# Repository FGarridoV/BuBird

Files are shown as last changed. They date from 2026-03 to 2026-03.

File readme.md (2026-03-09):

# 🐦 BuBird - Smart Birdhouse Observatory
*Welcome to the nest 🪺!*

**BuBird** is an open-source hardware/software project designed to observe the life cycle of local birds in real-time, with near-zero latency, and without invading their natural space. The system combines solar energy and the efficiency of an **ESP32-CAM** with the processing power of a **Raspberry Pi**, offering live video streaming via WebRTC and an remote control Dashboard. 

This project can be a great way to learn many different concepts and topics around Maker and IT culture. At the end, you will be familiar with Docker containers, Cloudflare, Networking, RTSP and UPD server, Python and PlatformIO scripting, Web deployment, 3D printing, hardware setup and more.

In this repository we provide instructions and resources for everyone to implement this project. You are free to choose any bird house, however, we built this project on the [SWEDISH BIRD HOUSE](https://www.thingiverse.com/thing:2503022) contributed by [PurchenZuPoden](https://www.thingiverse.com/PurchenZuPoden/designs) on Thingiverse.

## 🧰 Project requirements

### Hardware
* **Raspberry Pi**: I've used a Pi5 8Gb, But I think with a 3B+, any Pi4 or higher will work.
* **ESP32-CAM**: I've used a clone of the AI Thinker [[buy]](https://amzn.eu/d/01GnobxX)
* **2.4Ghz WiFi Antenna** [[buy]](https://www.otronic.nl/nl/24ghz-wifi-antenne-met-sma-naar-ufl-ipex-connector.html)
* **PIR sensor HC-SR501** [[buy]](https://www.otronic.nl/nl/pir-sensor-hc-sr501-bewegingssensor.html)
* **Solar module CN3065** [[buy]](https://www.otronic.nl/nl/500ma-mini-solar-lipo-lithium-lader-modu-140567801.html)
* **LIPO Baterry** [[buy]](https://www.otronic.nl/nl/37v-4000mah-oplaadbare-lipo-lithium-polyemer-platt.html)
* **Solar Panel**
* **Wires**
* **House pole** [[buy]](https://amzn.eu/d/03isHCS7)

### Tools/materials
* **3D Printer**: I have one Ender3 (v1)
* **Soldering iron**
* **PLA Filament**: I've used Red, White, and Black.
* **Flux paste**
* **Sanding paper**

## 🛠️ System Architecture

The system uses different components to visualize the inside of the bird house autonomusly. The ESP32-CAM record the inside of the house and creates a RTSP server to stream the video to always plugged Raspberry Pi. The Pi captures this streaming and disponbilizes through a web page. The ESP inside the house is solar and battery powered, so, a movement sensor (PIR) controls the camera activity to save energy. Additionally, you can store photos and videos based on some rules to see them later. Finally, the system disponibilizes a local webpage, which it can be safely exposed using CloudFlare. The following Figure summary the full hardware architecture.

uses the ESP32-CAM to record what is happening in

## ✨ Key Features

* 🔋 **Energy Efficiency (Deep Sleep):** Interrupt-based system. The PIR sensor wakes the camera upon detecting motion and sends it to sleep after 1 minute of inactivity, maximizing battery life.
* ⚡ **Ultra-Low Latency Streaming:** Real-time video transmission using RTSP converted to WebRTC via MediaMTX, allowing you to watch the nest without delay.
* 🧠 **State Machine (Auto/Manual):** Take remote control of the camera via UDP, overriding the PIR sensor to keep the system awake on demand.
* 💡 **Soft Flash (PWM):** Gradual toggling of the camera's LED to avoid scaring the birds or causing power spikes (*Brownouts*).
* ☁️ **Over-The-Air Updates (OTA On-Demand):** Integrated with ElegantOTA. The internal web server only spins up when manually activated, freeing up valuable RAM during normal operation.
* 🛡️ **Secure Web Dashboard:** Responsive, multilingual (EN/ES) UI hosted on Nginx with a password-protected control panel. Includes dynamic, real-time system log reading.
* 🪨 **Bulletproof Firmware:** C++ code (PlatformIO) optimized with core separation (FreeRTOS), forced PSRAM, and a 160MHz clock speed to prevent overheating and crashes (*Guru Meditation* errors).

---

## 🛠️ System Architecture

The project is divided into two main blocks:

### 1. The Eye (ESP32-CAM)

Programmed in PlatformIO (`C++`). Manages the camera, PIR sensor, and Wi-Fi connection. It streams RTSP video and communicates with the backend via UDP packets (for logging and receiving commands).

### 2. The Brain (Raspberry Pi / Docker Server)

Orchestrates three Docker containers:

* **MediaMTX:** Receives the RTSP stream from the ESP32-CAM and serves it to the web via WebRTC.
* **Comms Server (Python):** A lightweight UDP/HTTP server that saves logs, auto-discovers the camera's IP, securely verifies web passwords, and sends control commands to the ESP32.
* **Nginx:** Serves the web frontend (HTML/JS/CSS) where users can watch the nest and interact with the admin panel.

---

## 🧰 Hardware Requirements

* 1x **AI-Thinker ESP32-CAM** board (with OV2640 camera module).
* 1x **PIR** Motion Sensor (e.g., AM312 or SR501). Connected to `GPIO 13`.
* 1x Local Server / **Raspberry Pi** (To host the Docker containers).
* High-quality power supply (5V / 2A minimum) for the ESP32.

---

## 🚀 Installation & Deployment

### 1. Flashing the ESP32-CAM

1. Install [Visual Studio Code](https://code.visualstudio.com/) and the [PlatformIO](https://platformio.org/) extension.
2. Open the project's firmware folder.
3. Configure your Wi-Fi credentials and UDP server IP in `src/main.cpp`.
4. Connect the ESP32-CAM and click "Upload". PlatformIO will handle dependencies (ESP32-RTSPServer, ElegantOTA) automatically.

### 2. Deploying the Backend (Docker)

Make sure you have Docker and Docker Compose installed on your Raspberry Pi or local server.

```bash
# Clone the repository
git clone https://github.com/YOUR_USERNAME/BuBird.git
cd BuBird

# Start the services in the background
docker compose up -d

```

### 3. Configuring the Dashboard

1. By default, the admin control panel password is `nido`.
2. To change it, edit the `PASSWORD` variable in `comms/comms_server.py` and restart the container:
`docker restart bubird_comms`

---

## 🎮 Dashboard Usage

Access your Raspberry Pi's IP address in your web browser (e.g., `http://192.168.1.60`).
In the **"Live Cam"** section, expand the *Control Panel* and enter the password to access the Admin options:

* **Automatic:** Normal behavior governed by the PIR sensor.
* **Manual:** Keeps the camera awake and recording indefinitely.
* **Flash:** Turns the LED on/off gradually (Only available in Manual mode).
* **OTA:** Enables the `http://<ESP32_IP>/update` route to flash new firmware over Wi-Fi (Only available in Manual mode).
* **Sleep:** Forces an immediate Deep Sleep.

The system logs terminal on the page interprets these actions in real-time and updates the system status icons accordingly (Sleeping, Live, ⚙️, 🖐️, 💡, ☁️).

---

## 📜 License

This project is open-source. Feel free to clone it, modify it, and use it to observe wildlife in your own backyard!

*Developed with ☕, lots of C++ code, and a passion for nature.*

---

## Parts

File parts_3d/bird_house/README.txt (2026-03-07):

SWEDISH BIRD HOUSE by PurchenZuPoden on Thingiverse: https://www.thingiverse.com/thing:2503022

Summary:
This is a bird house designed to look like a traditional Swedish cottage with a small front porch.You can decide if you want to print the house shell as one piece:gehaeuse_v2or you can print the house shell in 3 parts:Floor: boden_v2Sidewall 1: fasssade_01Sidewall 2: fasssade_02_v2There are also two mounting plates for the house available:montageleiste | for screw mounting (M6 or similar)montageleiste_2 | for zip tie, wire or string mounting What you need:Patience ( My printing time was ~100h)Super GlueA drinking straw (5mm Outer Diameter) for the roof gutterA M6 Screw and nut or something similar to mount the birdhouse to the mounting braket4 M4 Nuts and 4 Screws for the detachable roof I have also used black nail polish and painted the surface for the window and door opening black before i glued the parts to the house.Additional notes:The standard birdhouse hole size is 30mm (einflugring_gewinde) and 45mm (einflugring). Please have a look here for different birdhouse hole sizes if you want to attract a specific bird.: https://www.thespruce.com/bird-house-hole-sizes-386641http://www.vogelhaus-nistkasten.de/nistkaesten/einflugloch-nistkasten/ (For german birds)Please make sure to add support, when you are printing the roof. The roof is the only part of the assembly that needs a little bit of support at the bottom of the print.If you have a woodpecker close by the chances are high, that he will like the sound of the birdhouse and will tear big holes in the walls. It happened to me already two times. I really don't have a solution for that. I printed the  3rd house now with almost 100% infill for the walls. I hope this will help.UPDATE 1:There is a new assembly for the birdhouse hole. (SCREW: einflugring_gewinde  and NUT: einflugring_mutter). You can easily change the hole size for a specific bird type e.g. with the Microsoft 3D Builder.UPDATE 2:If someone does not want to have the water reservoir on the bird house I have added modified partsIf someone wants to have a specific hole diameter, you can use the new file "einflugring_gewinde_without_hole.stl" and add the hole with your specific diameter e.g. with the free Microsoft 3D Builder Software

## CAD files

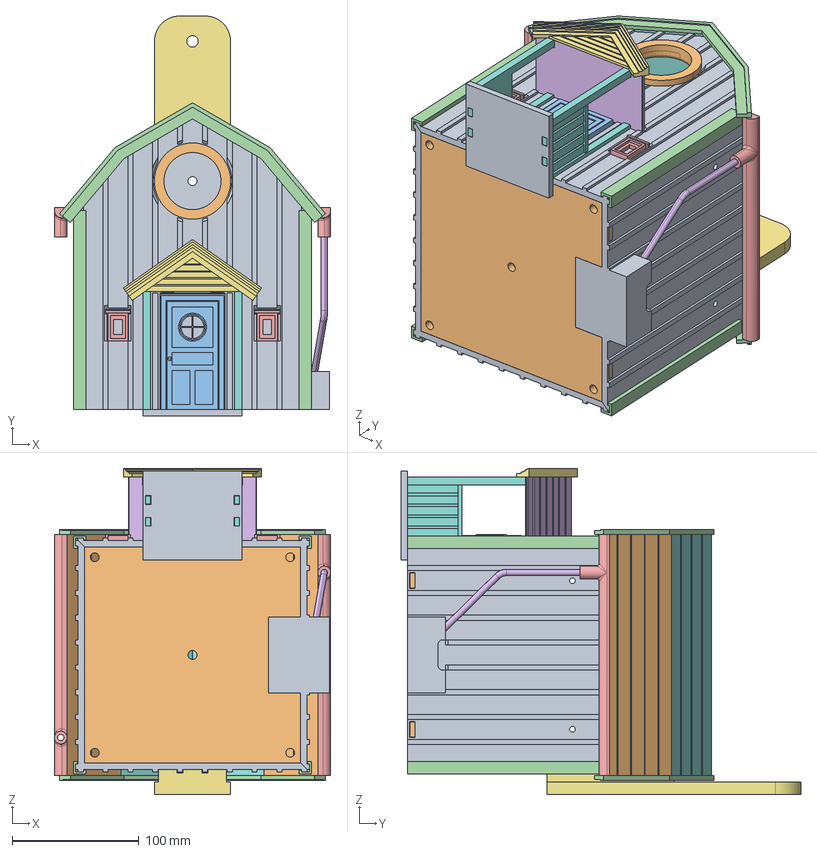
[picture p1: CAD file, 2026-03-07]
parts_3d/bird_house/files/vogelhaus_asm.stp
217.6 x 315.0 x 257.0 mm
FASSSADE_01
EINFLUGRING
TUER
KANTEN x 4
FENSTER_KLEIN x 2
FRONTDACH
FRONTDACHBLENDE
SEITENWAND
SSEITENWAND
FRONTBODEN
DACH_UNTEN
DACHUNTEN_SPIEGEL
DACH_OBEN x 2
DACHBLENDE x 2
DACHRINNE x 2
STROHHALM_AF0
MONTAGELEISTE
DACH_KOMPLETT
FASSSADE_02
BODEN
HOUSE_MOUNT_CABLE_TIES

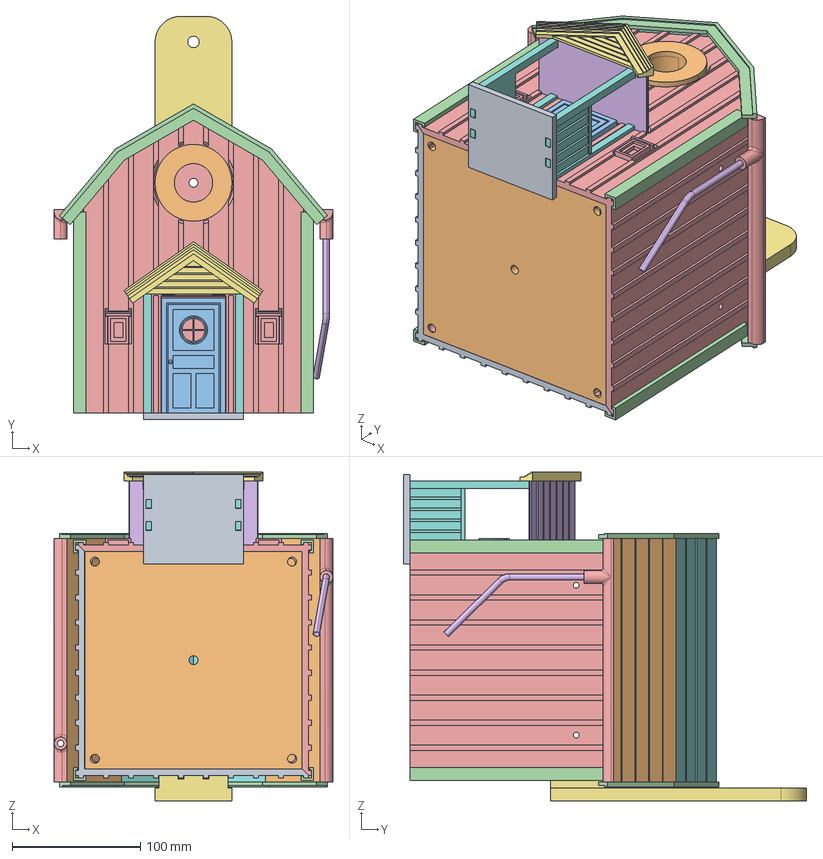
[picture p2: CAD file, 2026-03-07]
parts_3d/bird_house/files/vogelhaus_asm_without_water_reservoir.stp
217.6 x 315.0 x 257.0 mm
FASSSADE_01
EINFLUGRING_GEWINDE
TUER
KANTEN x 4
FENSTER_KLEIN x 2
FRONTDACH
FRONTDACHBLENDE
SEITENWAND
SSEITENWAND
FRONTBODEN
DACH_UNTEN
DACHUNTEN_SPIEGEL
DACH_OBEN x 2
DACHBLENDE x 2
DACHRINNE x 2
STROHHALM_AF0
MONTAGELEISTE
DACH_KOMPLETT
FASSSADE_02
BODEN
HOUSE_MOUNT_CABLE_TIES
EINFLUGRING_MUTTER
GEHAEUSE_FRONT

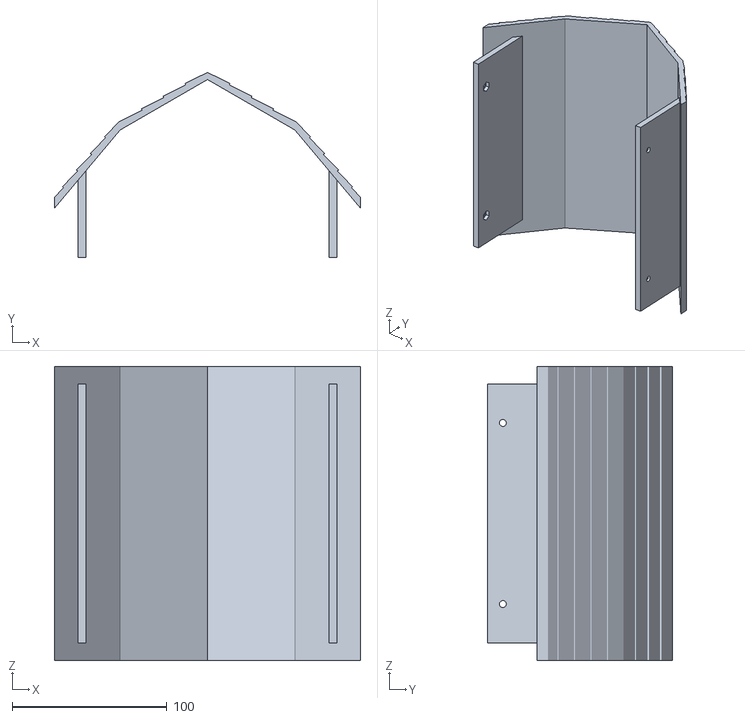
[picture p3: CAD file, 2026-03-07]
parts_3d/bird_house/files/dach_komplett.stl
197.6 x 119.6 x 190.0

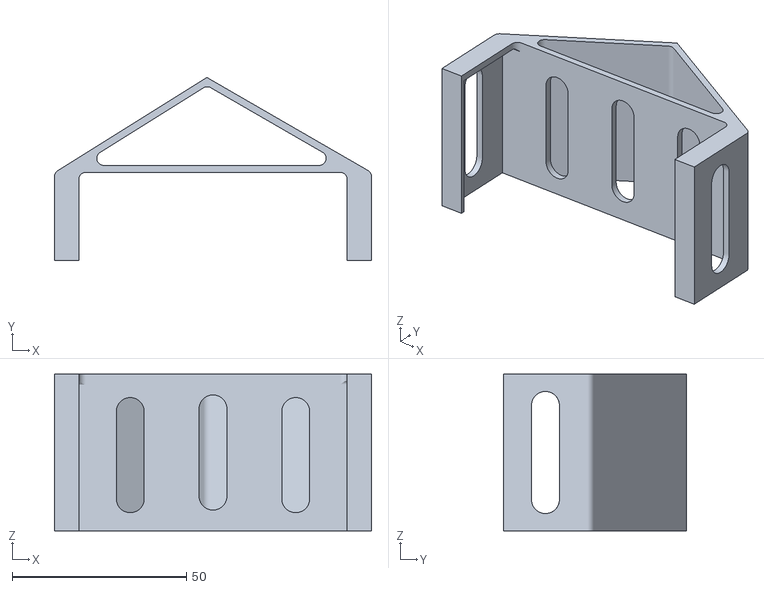
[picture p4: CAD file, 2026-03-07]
parts_3d/camera_holder/camera_holder.stl
90.9 x 52.5 x 45.0

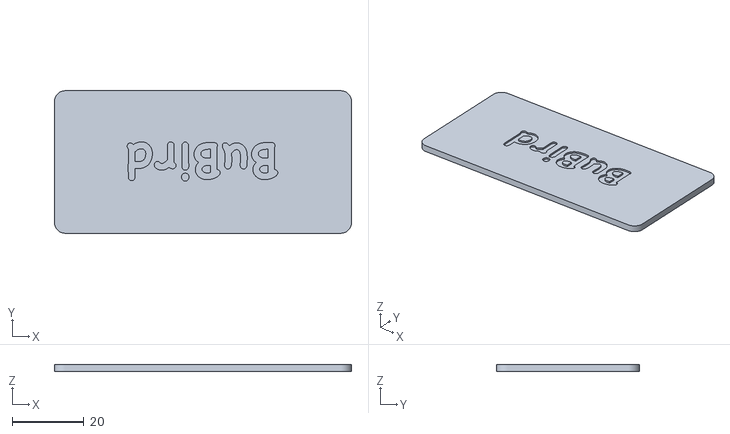
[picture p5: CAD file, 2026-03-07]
parts_3d/esp_pir_case/lid.stl
82.7 x 39.7 x 2.00

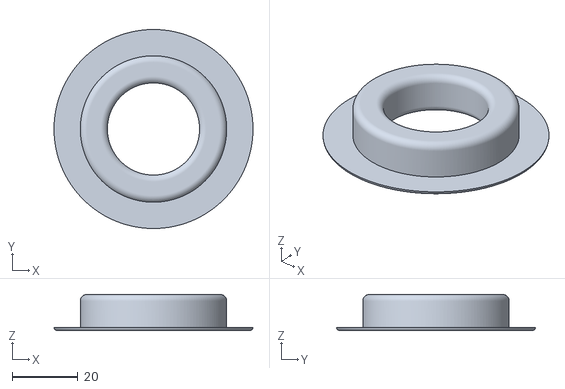
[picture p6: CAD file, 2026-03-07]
parts_3d/hole_reducer/hole_reducer.stl
60.5 x 60.5 x 11.0

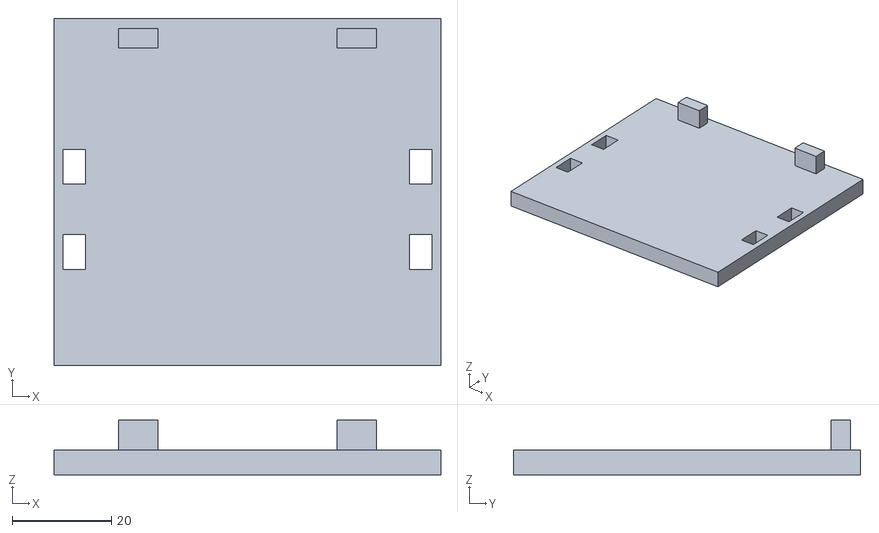
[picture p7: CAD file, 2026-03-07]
parts_3d/bird_house/files/frontboden.stl
78.0 x 70.0 x 11.0

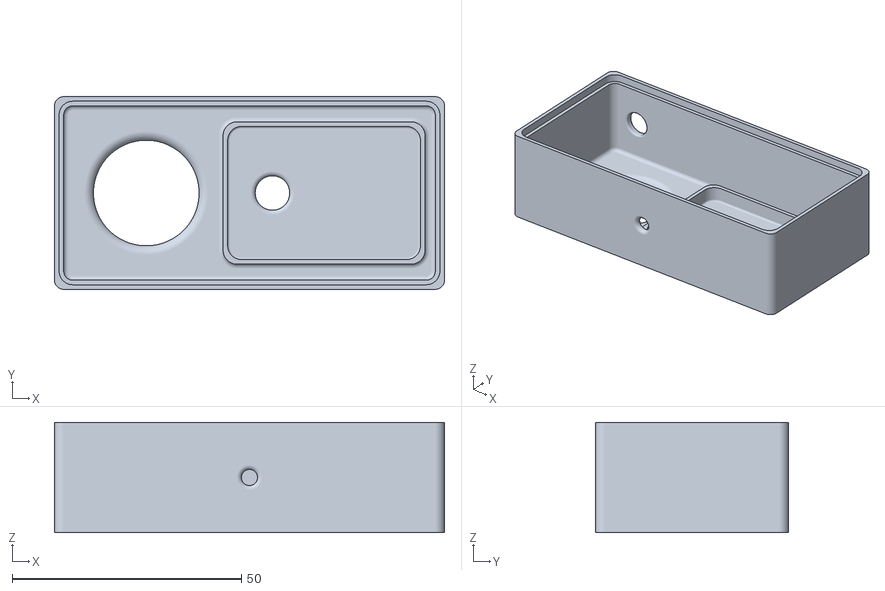
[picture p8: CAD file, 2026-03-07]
parts_3d/esp_pir_case/case.stl
85.0 x 42.0 x 24.0

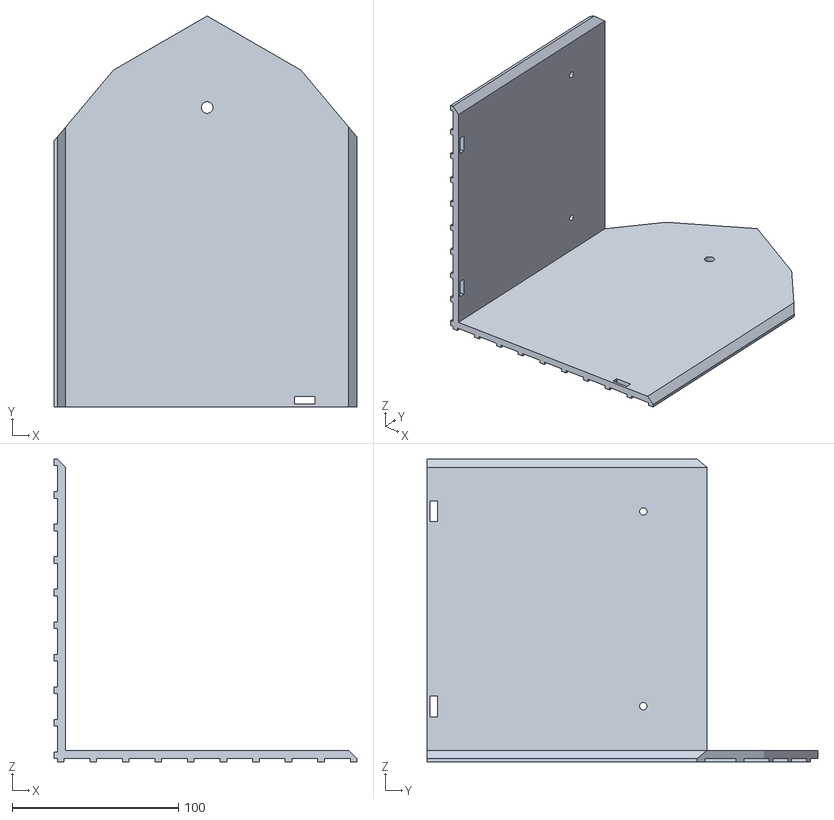
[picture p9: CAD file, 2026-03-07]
parts_3d/bird_house/files/fasssade_02_v2.stl
182.0 x 235.0 x 182.0

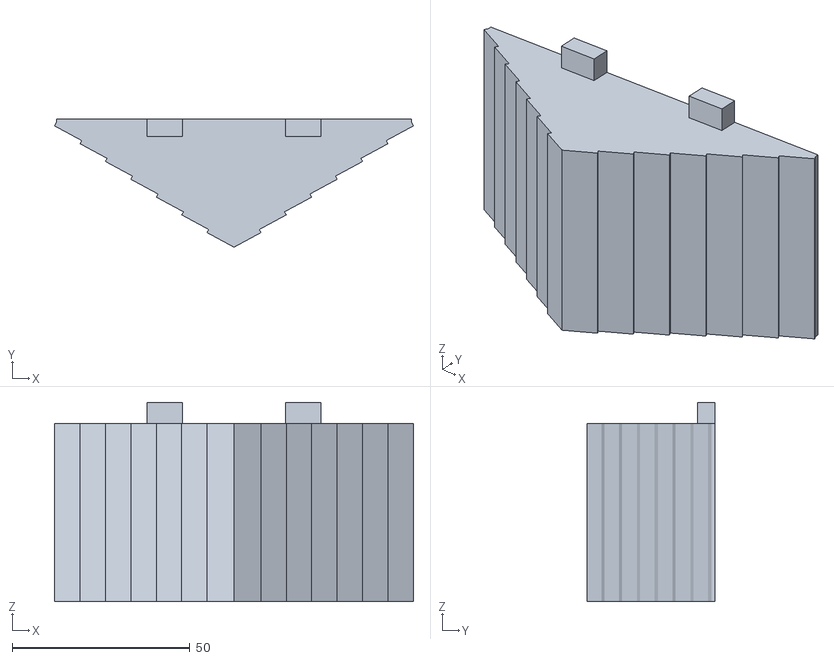
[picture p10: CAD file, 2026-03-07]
parts_3d/bird_house/files/frontdach.stl
100.9 x 36.1 x 56.0

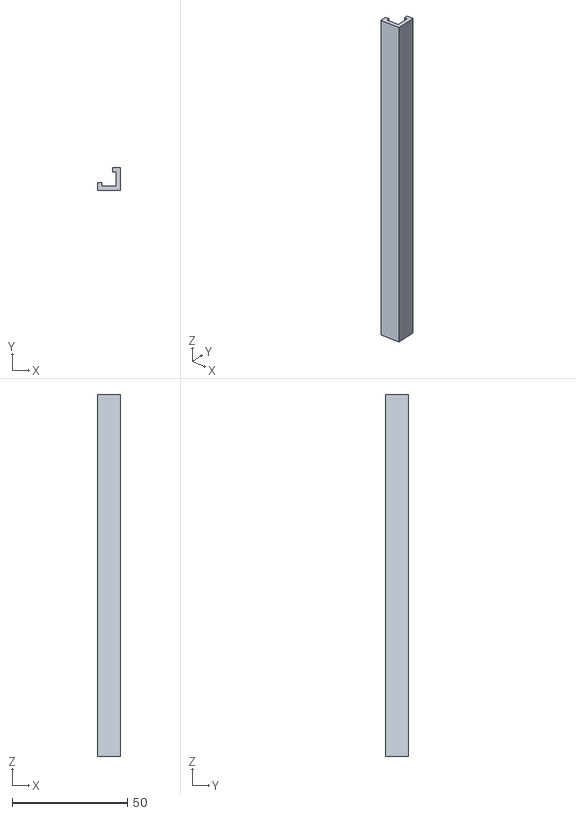
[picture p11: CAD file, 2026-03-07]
parts_3d/bird_house/files/kanten.stl
10.0 x 10.0 x 157.0

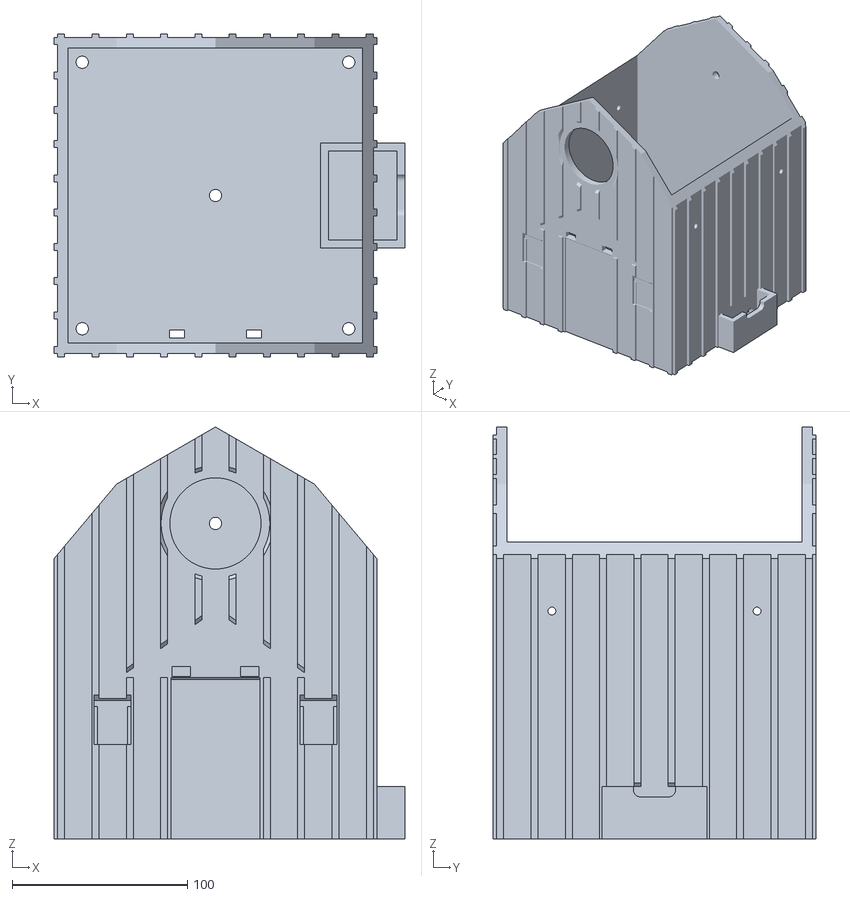
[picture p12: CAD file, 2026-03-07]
parts_3d/bird_house/files/gehaeuse_v2.stl
200.0 x 184.0 x 235.0

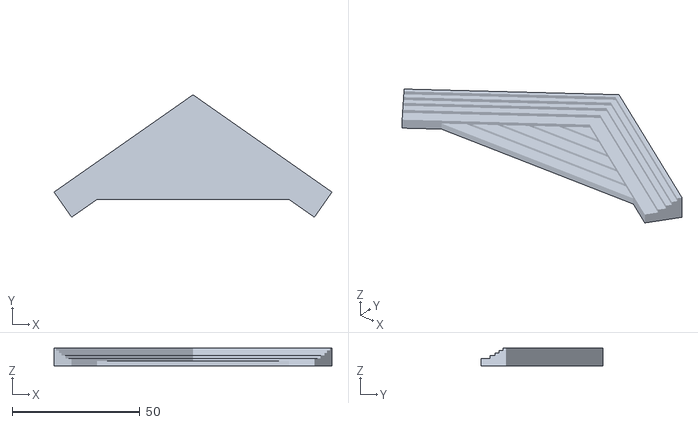
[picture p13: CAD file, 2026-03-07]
parts_3d/bird_house/files/frontdachblende.stl
108.8 x 47.9 x 7.00

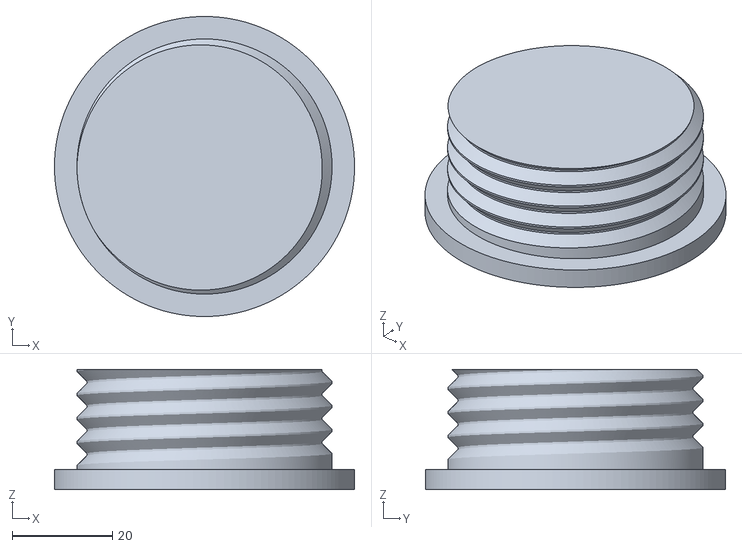
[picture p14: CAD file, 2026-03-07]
parts_3d/bird_house/files/einflugring_gewinde_without_hole.stl
60.0 x 60.0 x 24.0

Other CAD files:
parts_3d/bird_house/files/dachblende.stl
parts_3d/bird_house/files/fenster_klein.stl
parts_3d/bird_house/files/fasssade_01.stl
parts_3d/bird_house/files/montageleiste_2.stl
parts_3d/bird_house/files/boden_v2.stl
parts_3d/bird_house/files/boden_v2_without_water_reservoir.stl
parts_3d/bird_house/files/dachrinne.stl
parts_3d/bird_house/files/einflugring.stl
parts_3d/bird_house/files/einflugring_gewinde.stl
parts_3d/bird_house/files/einflugring_mutter.stl
parts_3d/bird_house/files/fasssade_01_without_water_reservoir.stl
parts_3d/bird_house/files/gehaeuse_v2_without_water_reservoir.stl
parts_3d/bird_house/files/montageleiste.stl
parts_3d/bird_house/files/seitenwand_links.stl
parts_3d/bird_house/files/seitenwand_rechts.stl
parts_3d/bird_house/files/tuer.stl

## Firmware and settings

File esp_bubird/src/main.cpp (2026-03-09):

#include <Arduino.h>           
#include "esp_camera.h"
#include <WiFi.h>
#include <ESP32-RTSPServer.h>
#include "time.h" 
#include <WiFiUdp.h>
#include "soc/soc.h"           
#include "soc/rtc_cntl_reg.h"  
#include "soc/rtc.h"
#include <WebServer.h>
#include <ElegantOTA.h>

const char* ssid = "SSID";
const char* password = "PASSWORD";

// --- UDP CONFIGURATION ---
WiFiUDP udp;
IPAddress udpAddress(192, 168, 1, 60); // IP de tu Raspberry Pi
const int udpPort = 6666;

// --- TIME CONFIGURATION (NTP) ---
const char* ntpServer = "pool.ntp.org";
const char* time_zone = "CET-1CEST,M3.5.0,M10.5.0/3";

// --- PIR & FLASH CONFIGURATION ---
#define PIR_PIN GPIO_NUM_13
#define WAIT_TIME_MS 60000
#define SLEEP_TIME_US 30ULL * 60ULL * 1000000ULL // 30 minutes in microseconds
#define FLASH_PIN 4

// --- AI-Thinker Pins ---
#define PWDN_GPIO_NUM     32
#define RESET_GPIO_NUM    -1
#define XCLK_GPIO_NUM      0
#define SIOD_GPIO_NUM     26
#define SIOC_GPIO_NUM     27
#define Y9_GPIO_NUM       35
#define Y8_GPIO_NUM       34
#define Y7_GPIO_NUM       39
#define Y6_GPIO_NUM       36
#define Y5_GPIO_NUM       21
#define Y4_GPIO_NUM       19
#define Y3_GPIO_NUM       18
#define Y2_GPIO_NUM        5
#define VSYNC_GPIO_NUM    25
#define HREF_GPIO_NUM     23
#define PCLK_GPIO_NUM     22

RTSPServer rtspServer;
int quality = 12; 

// --- STATE MACHINE VARIABLES ---
enum SystemMode { MODE_AUTO, MODE_MANUAL };
SystemMode currentMode = MODE_AUTO; // Starts in auto mode

unsigned long firstDetection = 0; 
unsigned long lastActivity = 0;  
bool previousMotion = false; 

// --- OTA SERVER ---
WebServer server(80);
bool otaEnabled = false;

// --- SENDING LOGS FUNCTION ---
void remoteLog(String msg) {
  Serial.println(msg); 
  if (WiFi.status() == WL_CONNECTED) {
    udp.beginPacket(udpAddress, udpPort);
    udp.print(msg);
    udp.endPacket();
  }
}

// --- VIDEO TASK ---
void sendVideo(void* pvParameters) { 
  while (true) { 
    if(!otaEnabled && rtspServer.readyToSendFrame()) {
      camera_fb_t* fb = esp_camera_fb_get();
      if (fb) {
        rtspServer.sendRTSPFrame(fb->buf, fb->len, quality, fb->width, fb->height);
        esp_camera_fb_return(fb);
      }
    }
    vTaskDelay(pdMS_TO_TICKS(50)); 
  }
}

void printCurrentTime() {
  struct tm timeinfo;
  if(!getLocalTime(&timeinfo)){
    remoteLog("  -> [Clock] Failed to obtain time from NTP server.");
    return;
  }
  char timeString[64];
  strftime(timeString, sizeof(timeString), "%Y-%m-%d %H:%M:%S", &timeinfo);
  remoteLog("  -> [Clock] Detection Date & Time: " + String(timeString));
}

// --- UDP COMMANDS LISTENER ---
void listenForCommands() {
  int packetSize = udp.parsePacket();
  if (packetSize) {
    char incoming[255];
    // Prevent Buffer Overflow: Read up to 254 bytes to leave room for the null terminator.
    int len = udp.read(incoming, 254);
    if (len > 0) incoming[len] = 0;
    
    String command = String(incoming);
    command.trim(); // Clean invisible spaces or newlines

    if (command == "MODE:MANUAL") {
      currentMode = MODE_MANUAL;
      remoteLog("[SYSTEM] Changing to MANUAL Mode (PIR disabled).");
    } 
    else if (command == "MODE:AUTO") {
      currentMode = MODE_AUTO;
      lastActivity = millis(); // Reset timer
      remoteLog("[SYSTEM] Changing to AUTO Mode (PIR enabled).");
    }
    else if (command == "FLASH:ON" && currentMode == MODE_MANUAL) {
      remoteLog("[FLASH] Turning ON gradually...");
      for(int i = 0; i <= 30; i++) { 
        ledcWrite(FLASH_PIN, i); 
        delay(30); 
      }
    }
    else if (command == "FLASH:OFF" && currentMode == MODE_MANUAL) {
      remoteLog("[FLASH] Turning OFF gradually...");
      for(int i = 30; i >= 0; i--) {
        ledcWrite(FLASH_PIN, i); 
        delay(30);
      }
    }
    else if (command == "OTA:ON" && currentMode == MODE_MANUAL) {
      server.on("/", []() { server.send(200, "text/plain", "BuBird OTA Server Ready"); });
      ElegantOTA.begin(&server);
      // Disable the watchdog timer so it doesn't kill the upload process
      ElegantOTA.setAutoReboot(true);
      server.begin();
      otaEnabled = true;
      remoteLog("[OTA] Server STARTED. Video Streaming PAUSED for safety.");
      remoteLog("[OTA] Go to http://" + WiFi.localIP().toString() + "/update");
    }
    else if (command == "OTA:OFF" && otaEnabled) {
      server.stop();
      otaEnabled = false;
      remoteLog("[OTA] Server STOPPED. Video Streaming RESUMED.");
    }
    else if (command == "REBOOT" && currentMode == MODE_MANUAL) {
      remoteLog("[SYSTEM] REBOOT command received. Restarting...");
      delay(1000);
      ESP.restart();
    }
  }
}

void setup() {
  // --- BROWNOUT DETECTOR SHIELD (CRITICAL FOR FLASH) ---
  WRITE_PERI_REG(RTC_CNTL_BROWN_OUT_REG, 0); 

  Serial.begin(115200);
  delay(1000); 
  
  remoteLog("\n\n=================================");
  remoteLog("   Starting BuBird PIR v3.0      ");
  
  // Imprimir razón de despertar
  esp_sleep_wakeup_cause_t wakeup_reason = esp_sleep_get_wakeup_cause();
  if (wakeup_reason == ESP_SLEEP_WAKEUP_TIMER) {
    remoteLog("   Wakeup Reason: TIMER (30 min) ");
  } else if (wakeup_reason == ESP_SLEEP_WAKEUP_EXT0) {
    remoteLog("   Wakeup Reason: PIR SENSOR     ");
  } else {
    remoteLog("   Wakeup Reason: NORMAL REBOOT  ");
  }
  remoteLog("=================================");

  if (!psramFound()) {
    Serial.println("PSRAM not found. Restarting...");
  }

// --- FLASH SETUP (PWM - CORE v3.x) ---
  ledcAttach(FLASH_PIN, 5000, 8); // Pin, Frequency (5kHz), Resolution (8 bits)
  ledcWrite(FLASH_PIN, 0);        // Write directly to PIN, OFF by default

  // Configure PIR for wake up
  pinMode(PIR_PIN, INPUT);
  esp_sleep_enable_ext0_wakeup(PIR_PIN, 1); 

  // Configure Timer for wake up (30 minutes)
  esp_sleep_enable_timer_wakeup(SLEEP_TIME_US);

  remoteLog("[1/5] Configuring camera pins...");
  camera_config_t config;
  config.ledc_channel = LEDC_CHANNEL_0;
  config.ledc_timer = LEDC_TIMER_0;
  config.pin_d0 = Y2_GPIO_NUM; config.pin_d1 = Y3_GPIO_NUM; config.pin_d2 = Y4_GPIO_NUM;
  config.pin_d3 = Y5_GPIO_NUM; config.pin_d4 = Y6_GPIO_NUM; config.pin_d5 = Y7_GPIO_NUM;
  config.pin_d6 = Y8_GPIO_NUM; config.pin_d7 = Y9_GPIO_NUM; config.pin_xclk = XCLK_GPIO_NUM;
  config.pin_pclk = PCLK_GPIO_NUM; config.pin_vsync = VSYNC_GPIO_NUM; config.pin_href = HREF_GPIO_NUM;
  config.pin_sccb_sda = SIOD_GPIO_NUM; config.pin_sccb_scl = SIOC_GPIO_NUM;
  config.pin_pwdn = PWDN_GPIO_NUM; config.pin_reset = RESET_GPIO_NUM;
  
  config.xclk_freq_hz = 10000000; 
  config.pixel_format = PIXFORMAT_JPEG;
  config.frame_size = FRAMESIZE_SVGA; 
  config.jpeg_quality = quality;
  config.fb_count = 2; 

  if (esp_camera_init(&config) != ESP_OK) { 
    remoteLog("[CRITICAL ERROR] Camera init failed. Restarting...");
    delay(3000);
    ESP.restart(); 
  }
  remoteLog("  -> Camera initialized successfully!");

  remoteLog("[2/5] Connecting to WiFi (" + String(ssid) + ")...");
  WiFi.mode(WIFI_STA); // Force Station mode to prevent random AP broadcasting
  WiFi.begin(ssid, password);
  
  uint8_t wifiRetries = 0;
  while (WiFi.status() != WL_CONNECTED && wifiRetries < 40) { 
    delay(500); 
    Serial.print(".");
    wifiRetries++;
  }
  
  // Anti-Drain Mechanism: If WiFi is completely down, sleep and try later.
  if (WiFi.status() != WL_CONNECTED) {
    Serial.println("\n[CRITICAL ERROR] WiFi failed to connect. Sleeping to save power...");
    esp_deep_sleep_start();
  }

  remoteLog("\n  -> ESP connected to WiFi succesfully!");
  remoteLog("  -> ESP IP Assigned: " + WiFi.localIP().toString());
  
  remoteLog("[3/5] Synchronizing clock with Internet...");
  configTzTime(time_zone, ntpServer);
  delay(1000);
  printCurrentTime();

  remoteLog("[4/5] Starting RTSP Server & UDP Listener...");
  rtspServer.transport = RTSPServer::VIDEO_ONLY;
  rtspServer.init();
  udp.begin(udpPort); // Start listening for commands on port 6666

  remoteLog("[5/5] Starting video transmission task...");
  xTaskCreatePinnedToCore(sendVideo, "VideoTask", 1024 * 8, NULL, 1, NULL, 0); 
  
  remoteLog("=================================");
  remoteLog("          SYSTEM OK              ");
  remoteLog("=================================");
  
  firstDetection = millis(); 
  lastActivity = millis(); 
}

void loop() {
  // 1. Always listen for remote commands
  listenForCommands();

  // 2. Process OTA Server request if enabled
  if (otaEnabled) {
    server.handleClient();
    ElegantOTA.loop();
  }

  // 3. Logic based on Operation Mode
  if (currentMode == MODE_AUTO) {
    bool motionDetected = digitalRead(PIR_PIN);

    if (motionDetected == HIGH) {
      lastActivity = millis(); 
      
      if (!previousMotion) { 
        struct tm timeinfo;
        String timeStamp = "";
        
        if(getLocalTime(&timeinfo)) {
          char timeString[64];
          strftime(timeString, sizeof(timeString), "%Y-%m-%d %H:%M:%S", &timeinfo);
          timeStamp = "[" + String(timeString) + "] ";
        }
        
        remoteLog(timeStamp + "[PIR] Motion detected! Keeping system active...");
        previousMotion = true;
      }
    } else {
      previousMotion = false;
    }

    if (millis() - lastActivity > WAIT_TIME_MS) {
      unsigned long presenceSeconds = (lastActivity - firstDetection) / 1000;
      remoteLog("\n=================================");
      remoteLog("[STATS] Total presence time in nest: " + String(presenceSeconds) + " seconds.");
      remoteLog("=================================");
      remoteLog("[SLEEP] 1 minute without motion. Entering Deep Sleep for 30 minutes... Zzz");
      delay(1000);
      esp_deep_sleep_start(); 
    }
  }
  // In MODE_MANUAL, the loop simply ignores PIR and keeps the camera alive.

  // 4. WiFi security check (only reboot if NOT doing OTA to prevent interrupting upload)
  if (WiFi.status() != WL_CONNECTED && !otaEnabled) { 
    remoteLog("\n[ERROR] WiFi connection lost. Restarting to recover...");
    delay(2000);
    ESP.restart(); 
  }

  vTaskDelay(pdMS_TO_TICKS(100)); // Short delay so commands respond quickly
}

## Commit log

2026-03-07 ESP32 software
2026-03-07 STL 3D Parts
    [boden_v2.stl, boden_v2_without_water_reservoir.stl, camera_holder.stl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]
2026-03-07 adding new reboot function
    [main.cpp]
2026-03-09 Solvinf issue for OTA updates
    [main.cpp]
